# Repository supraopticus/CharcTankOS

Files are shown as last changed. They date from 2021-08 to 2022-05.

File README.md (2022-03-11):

# CharcTankOS

CharcTankOS is written in Python and used to control the function of a curing chamber for making charcuterie.  It reads and uploads data to Firebase so you will need to create a free account for that.  I intend to make an iOS app later so that I can view the data and change settings remotely.  I don't have any experience with android so that will not be on the agenda for me.

It is meant to run on a RaspberryPi and use the official 7in rPi touchscreen for a display.  The software is a work in progress and coding is a hobby for me so use at your own risk.  I understand that the layout of the code is a little messy.  I started to learn how to use classes in Python so you can tell which parts I wrote later on vs the earlier stuff.  Sorry for the mess, but it (mostly) works.

There are lines that need to be uncommented  / commented out depending on how you are controlling the TECs (peltiers). Just search for "MARK".  I'll try to come up with more detailed explanations as time goes on with the hope of doing a full write up of the project in the future.

For more details on the curing chamber construction, see my post on Reddit

You will also need to get image files for the up and down arrow to be placed in the working directory.  I used some from a program called icons8 called "sort-down.png" and "sort-up.png"  icons8 is a free download.

https://www.reddit.com/r/Charcuterie/comments/orfh1o/my_fully_automated_custom_made_charctank_powered/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

Edit 8/8/2021: Added STL for TEC manifold.  I printed it out of PETG 20% infill.  I think it could be made out of PLA, but I didnt know at the time how much heat would be generated and didnt want to run into issues of warping.  To install this, you will need a 4in hole saw.  I designed all the printed parts in Fusion360 so I will include the links to those files in case anyone wants to make modifications. While the box that holds all the electronics is functional, some of the screw holes are slightly off so they will need to be modified if you're super OCD.  I'm able to hold each board down with one or two screws, so that was good enough for me.  Plus the electroics box takes over a day to print and since it takes up most of the bed, it's very prone to warping at the edges even with my enclosure.    

Parts list:

TEC Modules: https://www.aliexpress.com/item/32974339055.html?spm=a2g0s.9042311.0.0.2eb04c4dGorHiL

12v 30A Power Supply: https://www.amazon.com/gp/product/B01M03VPT6/ref=ppx_yo_dt_b_asin_title_o05_s00?ie=UTF8&psc=1

DHT22 Temp / Humidity Sensors: https://www.amazon.com/gp/product/B0795F19W6/ref=ppx_yo_dt_b_asin_title_o07_s00?ie=UTF8&psc=1

ElectroCookie Solderable Breadboard PCB Board (Mini): https://www.amazon.com/gp/product/B07ZV8FWM4/ref=ppx_yo_dt_b_asin_title_o00_s00?ie=UTF8&psc=1

Closed Cell Foam: https://www.amazon.com/gp/product/B07SZ5CMN3/ref=ppx_yo_dt_b_asin_title_o00_s00?ie=UTF8&psc=1

Parts if using ESC for controling TECs:

Hobbywing QuicRun 1060: https://www.amazon.com/gp/product/B01LZHBJ85/ref=ppx_yo_dt_b_asin_title_o09_s00?ie=UTF8&psc=1

Parts if building custom controller for TECs: 

ElectroCookie PCB Prototype Board Large Solderable Breadboard: https://www.amazon.com/gp/product/B082KY5Y5Z/ref=ppx_yo_dt_b_asin_title_o00_s00?ie=UTF8&psc=1

IRF3708 N-Channel Power MOSFET: https://www.amazon.com/gp/product/B088NJXWZT/ref=ppx_yo_dt_b_asin_title_o00_s00?ie=UTF8&psc=1

Wire Terminals: https://www.amazon.com/gp/product/B07QRHJ489/ref=ppx_yo_dt_b_asin_title_o04_s00?ie=UTF8&psc=1

High-Speed MOSFET Power Driver: https://www.amazon.com/gp/product/B08C7V67TY/ref=ppx_yo_dt_b_asin_title_o07_s00?ie=UTF8&psc=1

Assorted resistors (10k and some 220ohm should work): https://www.amazon.com/gp/product/B072BL2VX1/ref=ppx_yo_dt_b_asin_title_o04_s01?ie=UTF8&psc=1

Ceramic Capacitors: https://www.amazon.com/gp/product/B0899TVNYB/ref=ppx_yo_dt_b_asin_title_o04_s01?ie=UTF8&psc=1

Electrolytic Capacitors: https://www.amazon.com/gp/product/B07KC99W2K/ref=ppx_yo_dt_b_asin_title_o03_s00?ie=UTF8&psc=1

Some Headder Pins.  I had them laying around

Wire.  Pref 20 or 22 awg

Optional parts:

Long Jumper Wires: https://www.amazon.com/gp/product/B07GD2PGY4/ref=ppx_yo_dt_b_asin_title_o07_s00?ie=UTF8&psc=1

Long Flex Cable for rPi Touchscreen: https://www.amazon.com/gp/product/B00M4DAQH8/ref=ppx_yo_dt_b_asin_title_o02_s00?ie=UTF8&psc=1

EC3 Banana Plugs: https://www.amazon.com/gp/product/B07BHJH3NG/ref=ppx_yo_dt_b_asin_title_o08_s01?ie=UTF8&psc=1

3D printed parts (Fusion 360):

TEC Manifold: https://a360.co/2VxvnbH

Electronics Box: https://a360.co/3CqsbQ5

DHT22 Sensor Cover: I didn't make this so I'm just including the STL in the files.  Credit to SciMonster on Thingiverse.

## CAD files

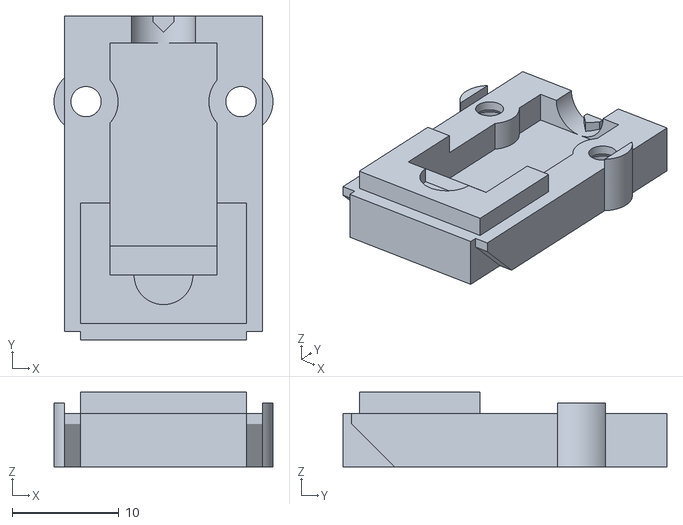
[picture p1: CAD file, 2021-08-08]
DHT22_top.stl
20.5 x 30.3 x 7.00

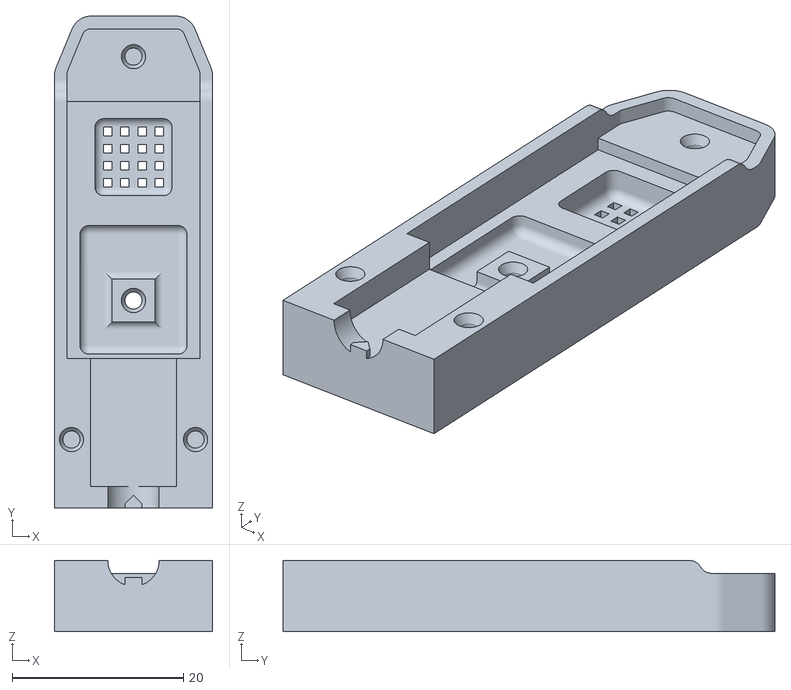
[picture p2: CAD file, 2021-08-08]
DHT22_bottom.stl
18.5 x 57.5 x 8.30

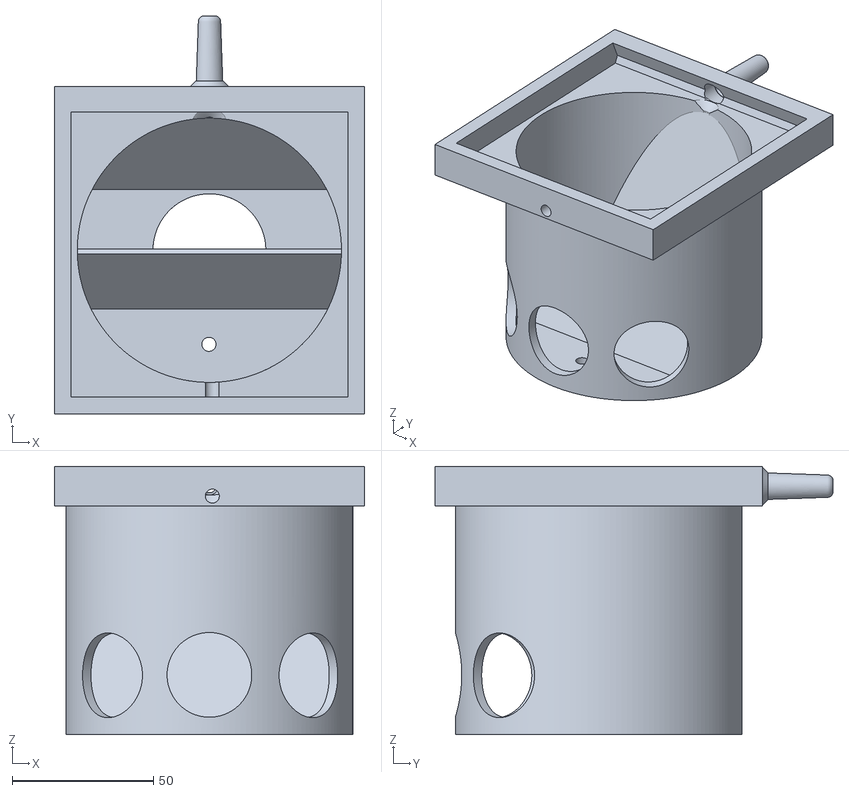
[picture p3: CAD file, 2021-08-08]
humidifierV2.stl
110.0 x 141.0 x 95.0

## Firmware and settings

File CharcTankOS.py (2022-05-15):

#! /usr/bin/env python3
# from logging import Filter

from tkinter import * #the GUI

from tkinter import font as tkFont
from tkinter import ttk
from time import strftime
import tkinter
from matplotlib.backend_bases import LocationEvent
import matplotlib.pyplot as plt
import matplotlib
from pandas.core import frame
matplotlib.use('TkAgg')
from matplotlib.backends.backend_tkagg import FigureCanvasTkAgg, NavigationToolbar2Tk
from matplotlib.figure import Figure
import matplotlib.animation as animation
from matplotlib import style
import matplotlib.pyplot as plt
from matplotlib.widgets import Cursor
import matplotlib.dates as mdates
import numpy as np
import pandas as pd
from datetime import datetime, timedelta
import sys
import os     #importing os library so as to communicate with the system
from time import sleep  #importing time library to make Rpi wait because its too impatient 

import firebase_admin
from firebase_admin import db
from firebase_admin import credentials
import json
from PIL import Image, ImageTk
#import threading
import logging





##MARK:
os.system ('sudo killall pigpiod') # just to make sure its not already running
os.system ("sudo pigpiod") #Launching GPIO library.  May need to run sudo killall pigpiod" if getting a binding error
sleep(1) # As i said it is too impatient and so if this delay is removed you will get an error
import pigpio #importing GPIO library for PWM.  can also be used for reading the DHT
import adafruit_dht as dht
from board import D2 # pin for temp and humidity

logger = logging.getLogger('root')
FORMAT = "[%(filename)s:%(lineno)s - %(funcName)20s() ] %(message)s"
logging.basicConfig(format=FORMAT)
logger.setLevel(logging.DEBUG)
#logger.setLevel(logging.CRITICAL) #uncomment if you want to disable debug messages


peltierEscMin = 1200
peltierEscMax = 1800
peltierEscMid = 1650
peltierESCPulseWidth = 700
##MARK:
# setup peltierESC
peltierPins = [13,19]
peltierPowerLevel = 0
peltierESC = 13  #Connect the peltierESC in this GPIO pin 
#setup multiple GPIOs because using PWM and Servo on the same will mess each other up
piGPIO = pigpio.pi() 
# piGPIO.hardware_PWM(peltierESC, PWMfreq=20000,PWMduty=1000000)
# piGPIO.set_PWM_dutycycle(peltierESC, 255)
# piGPIO.hardware_PWM(peltierESC, 20000, 0)

piGPIO.set_servo_pulsewidth(peltierESC, peltierEscMin) #for my ESC, this is all it needs to calibrate.  Check your manual.
dhtDevice = dht.DHT22(D2) # only init device once
# setup fridge and humidifier
fridgePin = 17
humidifierPin = 27
isFridgeOn = piGPIO.read(fridgePin) #read the pin state to see if the pin is on or off
isHumidifierOn = piGPIO.read(humidifierPin)#read the pin state to see if the pin is on or off

customPeltierControler = True
hOffset = 0 #used to calibrate humidity sensor
tOffset = 0
##MARK:
filename = '/home/pi/Python/CharcTankOS/CharcTankData.csv'
#filename = 'test.csv'
df = pd.read_csv(filename, index_col=0, parse_dates=True)
writeData = True

if len(df) > 69120: #check to see if there are more than 4 days of data in the list.
    n = len(df) - 69120
    df = df.iloc[n:]


root = Tk() #init tk
root.title("CharcTankOS")

root.geometry("800x480")
##MARK
root.attributes('-fullscreen', True)
root.config(cursor="none")

labelFont = tkFont.nametofont("TkDefaultFont")
labelFont.config(size= 12)
def_font = tkFont.nametofont("TkDefaultFont")
def_font.config(size=15)
bgColor = 'grey7'
fgColor = 'lightgrey'


screenWidth = 800

topBarFrame = Frame(root, height = 65, width = screenWidth, relief = 'raised', borderwidth = 2)
middleFrame = Frame(root, height = 330, width= screenWidth)
bottomBarFrame = Frame(root, height = 65, relief = 'raised', borderwidth = 2)


topBarFrame.pack(side= TOP)
middleFrame.pack(side = TOP)
bottomBarFrame.pack(side = BOTTOM)



#create figure as global var so that we can clear and update live
#for some reason the top and bottom bar add up to 90 lines and 26 lines of padding on the middle frame so set the fig height accordingly
#example "Figure(figsize = (5,3.2), dpi = 100)" will give you a figure that is 320 lines tall + ~26 lines padding for a total of 350
# fig = Figure(figsize = (5,3.22), dpi = 100) 
fig = Figure(figsize = (5,3.2), dpi = 100) 
ax = fig.add_subplot(111)

lf = ttk.Frame(middleFrame)
canvas = FigureCanvasTkAgg(fig, master = lf)
# filteredDF = pd.DataFrame()
graphDF = pd.DataFrame()
graphDFlen = 0
currentTemp = 0
currentRH = 0
averageTemp = 0
averageRH = 0

previousHumidityReading = 0
timerIndex = 0
settingsJSONLocation = 'settings.json'
try:
    with open(settingsJSONLocation, "r") as f:
        settingsJSON = json.load(f) #give settings a default value just in case firebase isnt reachable
        tempHighSet = settingsJSON['tempHighSet']
        tempLowSet = settingsJSON['tempLowSet']
        tempSet = settingsJSON['tempSet']
        midSetpointRH = settingsJSON['rhSet']
        hSetpointRH = settingsJSON['rhHigh']
        lSetpointRH = settingsJSON['rhLow']
        hOffset = settingsJSON['hOffset']
        humidifierOn=settingsJSON['humidifierOn']        
except Exception as e:
        logger.critical('Error opening settings.json')
        logger.critical(e)
#setup firebase, read and set values
try:
    databaseURL = { 'databaseURL' : "https://charctank-default-rtdb.firebaseio.com/"}
    cred = credentials.Certificate("charctank-firebase.json")
    firebase_admin.initialize_app(cred, databaseURL)
    currentDataRef = db.reference("/CurrentData/")
    historyRef = db.reference("/History/")
    settingsRef = db.reference("/Settings/")
    programsRef = db.reference("/Programs/")
except Exception as e:
    logger.critical('Error connecting to Firebase')
    logger.critical(e)

try:
    settingsJSON = settingsRef.get()
    tempHighSet = settingsJSON['tempHighSet']
    tempLowSet = settingsJSON['tempLowSet']
    tempSet = settingsJSON['tempSet']
    midSetpointRH = settingsJSON['rhSet']
    hSetpointRH = settingsJSON['rhHigh']
    lSetpointRH = settingsJSON['rhLow']
    hOffset = settingsJSON['hOffset']
    humidifierOn=settingsJSON['humidifierOn']
except Exception as e:
    logger.critical('Error with settings from Firebase')
    logger.critical(e)





def setPWMDutyCycle(percent):
    if percent > 100:
        percent = 100
    if percent < 0:
        percent = 0
    
    return percent * 10000
def setPeltierPower():
    for pin in peltierPins:
        piGPIO.hardware_PWM(pin, PWMfreq=30000, PWMduty=setPWMDutyCycle(peltierPowerLevel))
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

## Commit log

2021-08-07 Initial public commit.
    Program works as is right now. Currently working on implementing programs so that program will automate a fermentation process. This commit has a few sections commented out so that you can run it and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
2021-08-08 added STL for dehumidifier
    [humidifierV2.stl]
2022-04-02 Fixed error with humidifier not turning off
    [CharcTankOS.py]
2022-05-15 fixed logging error
    fixed logging error that would cause tkinter to freeze
    [CharcTankOS.py]
